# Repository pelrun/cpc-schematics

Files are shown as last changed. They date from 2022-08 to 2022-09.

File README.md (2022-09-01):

## Amstrad CPC6128 version 2 (MC0020x) schematic and pcb.

This is intended to be a reasonably accurate KiCad 6 transcription of the version 2 6128 pcb, with the 40010 Gate Array and the 24-pin disk data separator. The Amstrad service manuals don't bother to document this version, instead providing a mishmash of earlier and later revision schematics and pcb track layouts.

There are some liberties taken due to practical difficulties in reading the top layer of the PCB, so here's the priorities of this version:

- Schematic should match as closely as possible to the real board.
- All parts and part references and logical connectivity should match exactly.
- Part and via placement should match as closely as possible.
- Track routing should match closely on both sides of the pcb; all vias should be connected to the correct nets.
- Exact track poses may vary; original layout was done by hand and has varying angles; kicad layout is kept at 45 degrees.
- Track widths aren't correct everywhere; while the ground and power nets are handled by a netclass, a bunch of the tracks in the audio circuit need to have their widths manually adjusted.

Most part values should be correct, but I've not yet bothered to check any resistors - all values were copied from corresponding parts identified in the official schematics for the other revisions. Real values may be different, and additional resistors that are present but not documented elsewhere have been left with a value of "?".

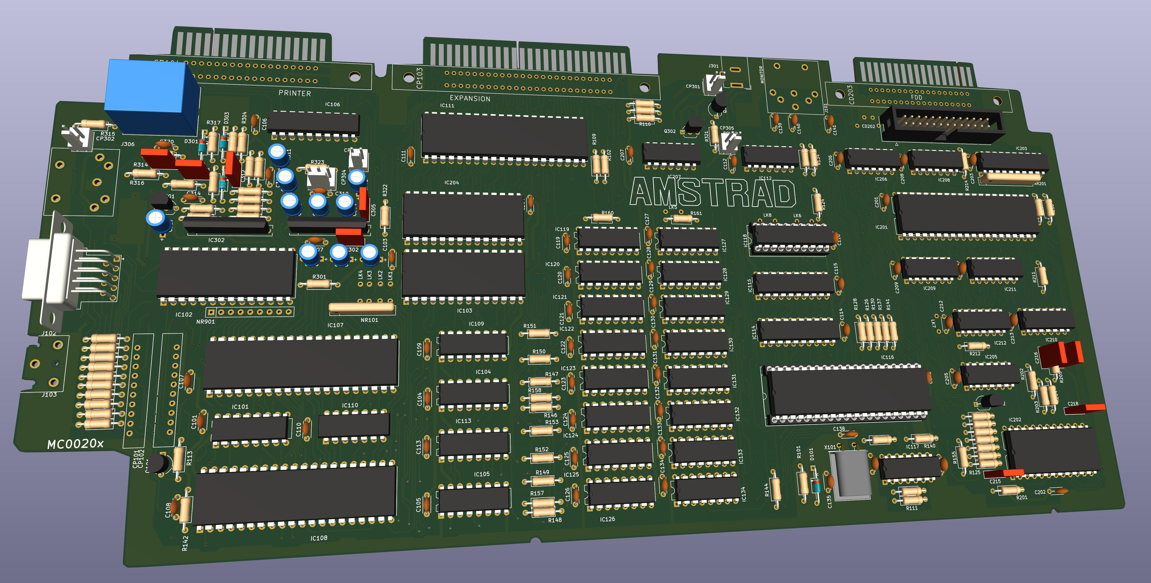
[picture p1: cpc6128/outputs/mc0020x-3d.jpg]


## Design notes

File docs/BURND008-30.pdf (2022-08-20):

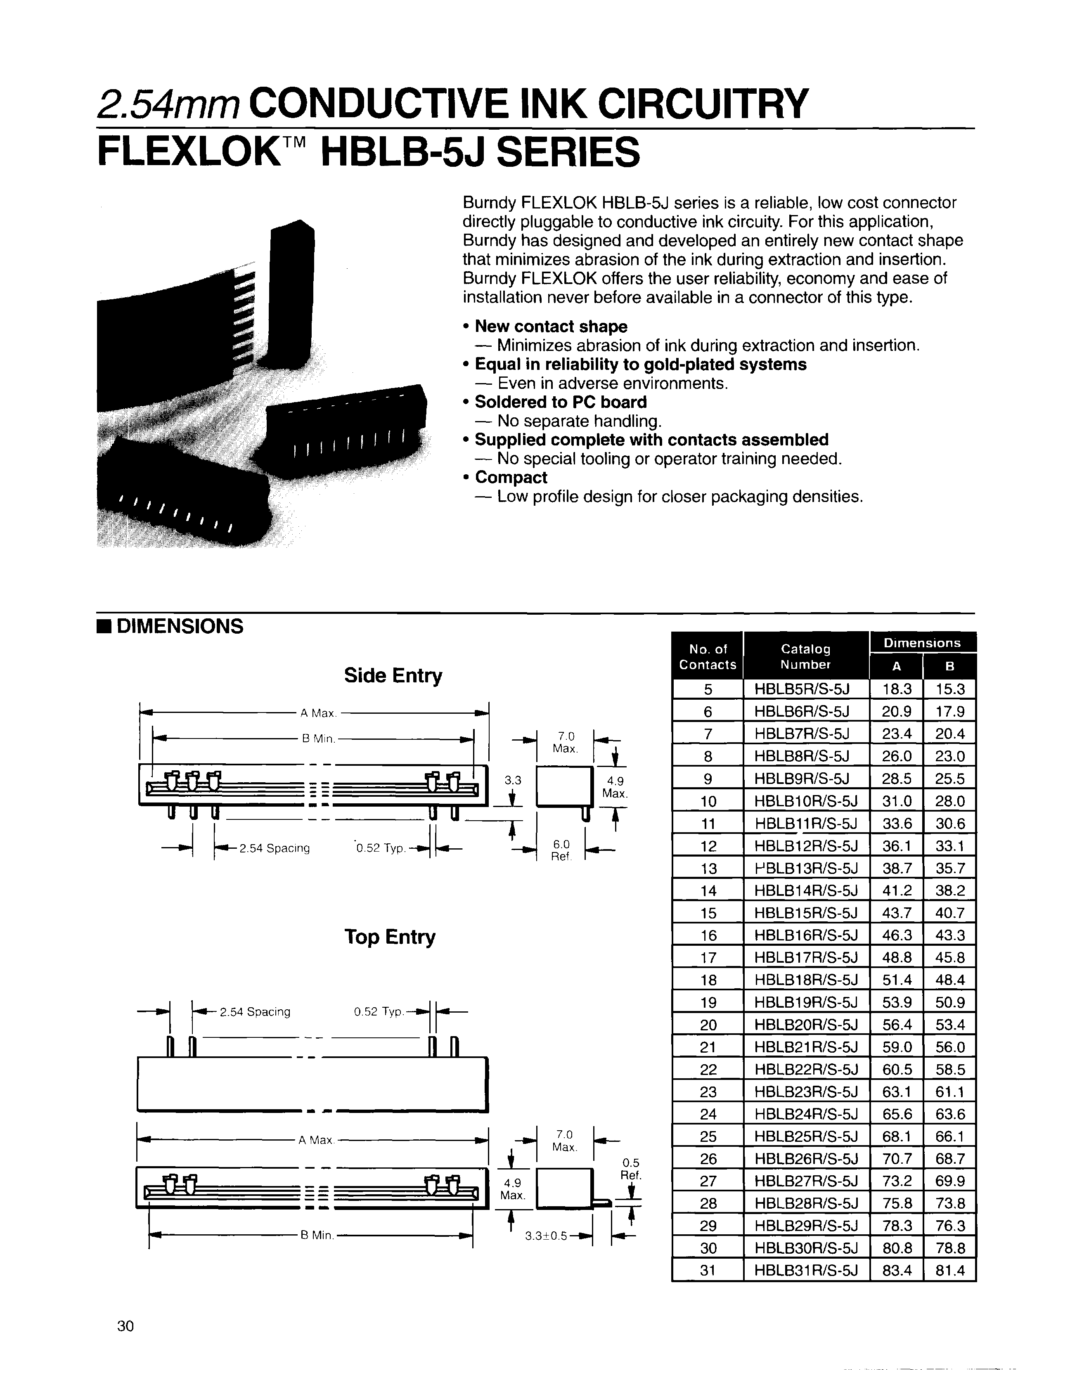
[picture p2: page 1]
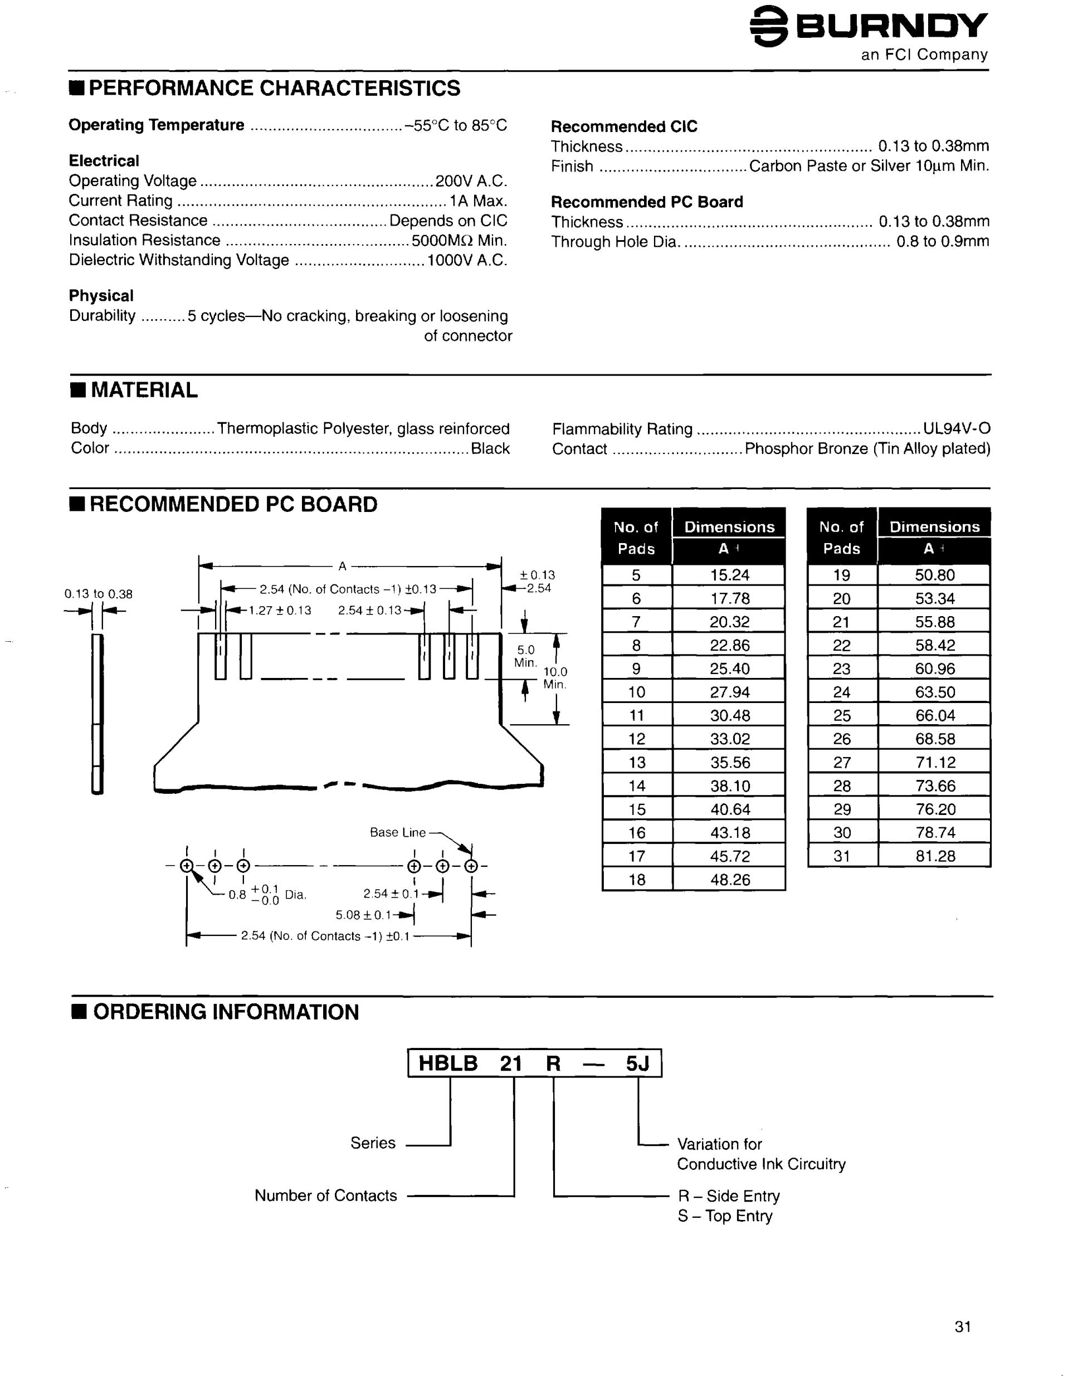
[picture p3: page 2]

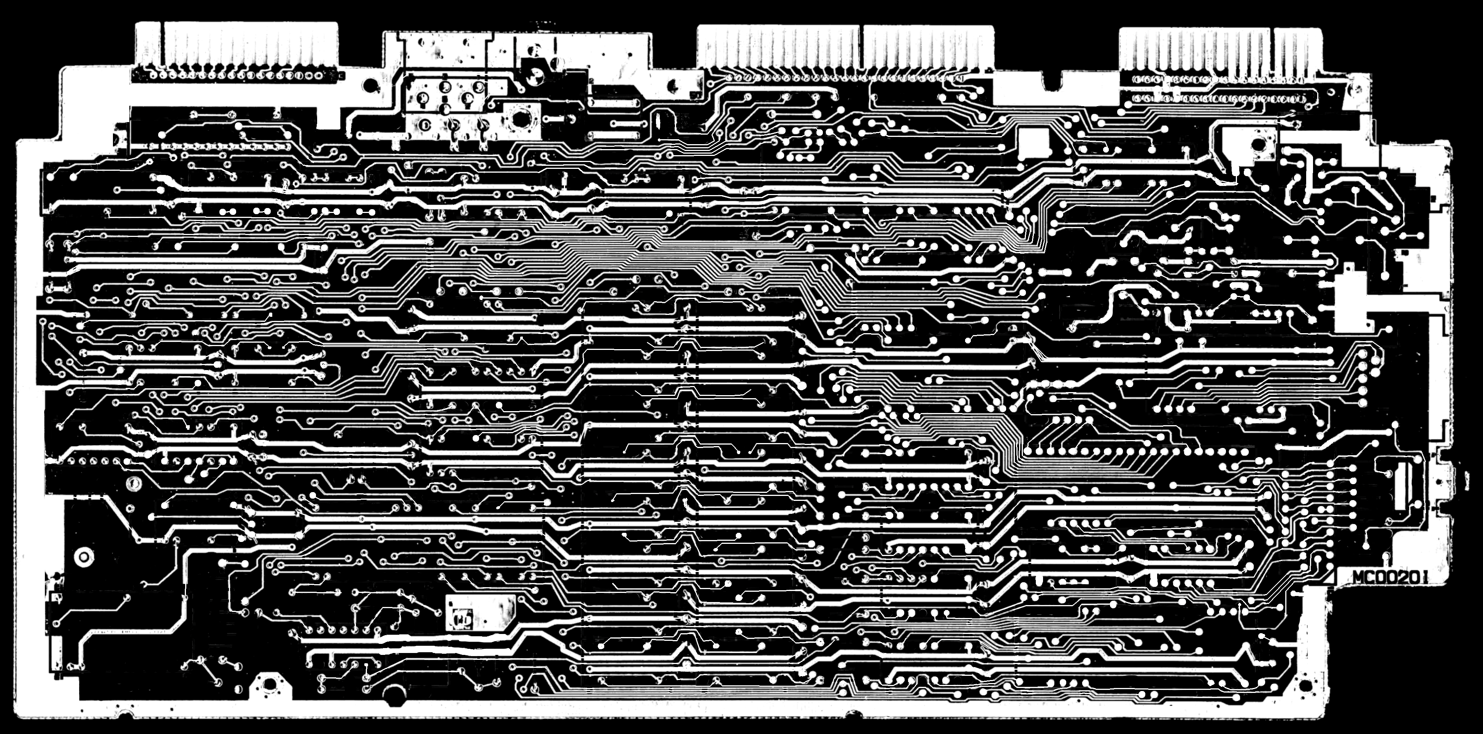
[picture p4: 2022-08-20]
docs/mc0020i-bcu.png

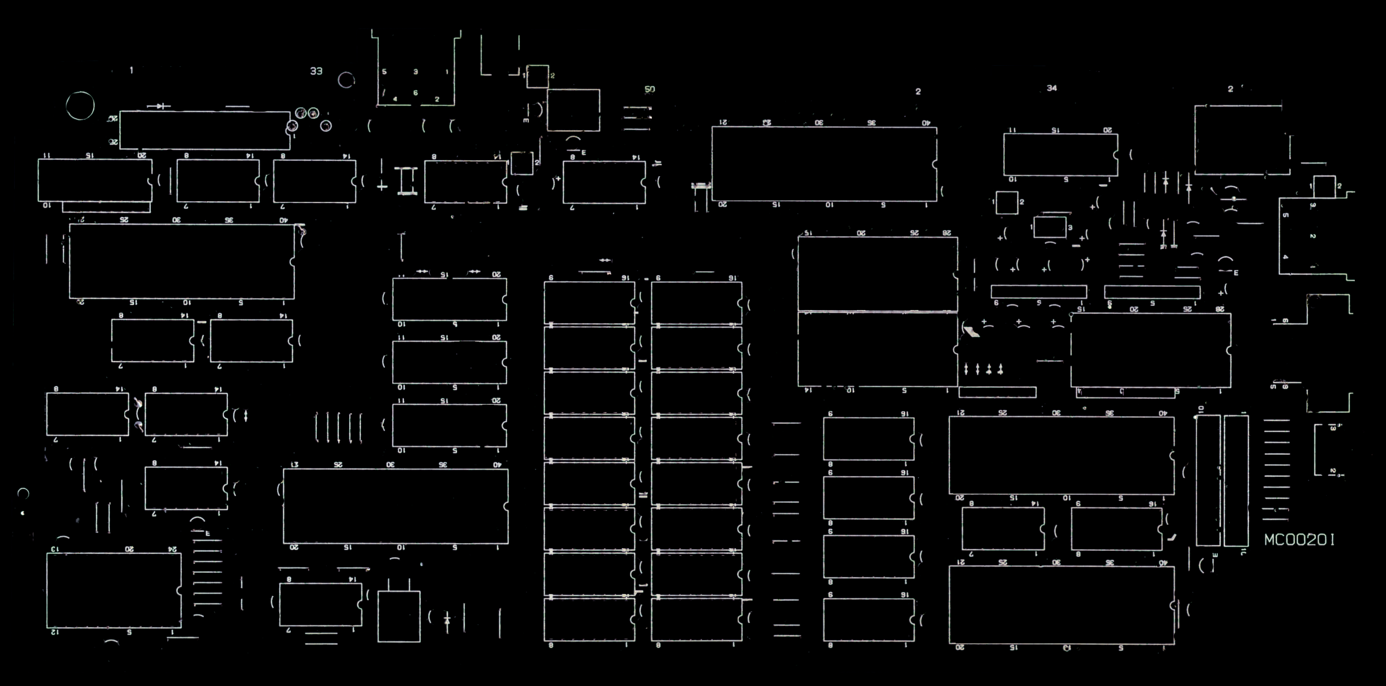
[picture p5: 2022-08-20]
docs/mc0020i-bsilks.png

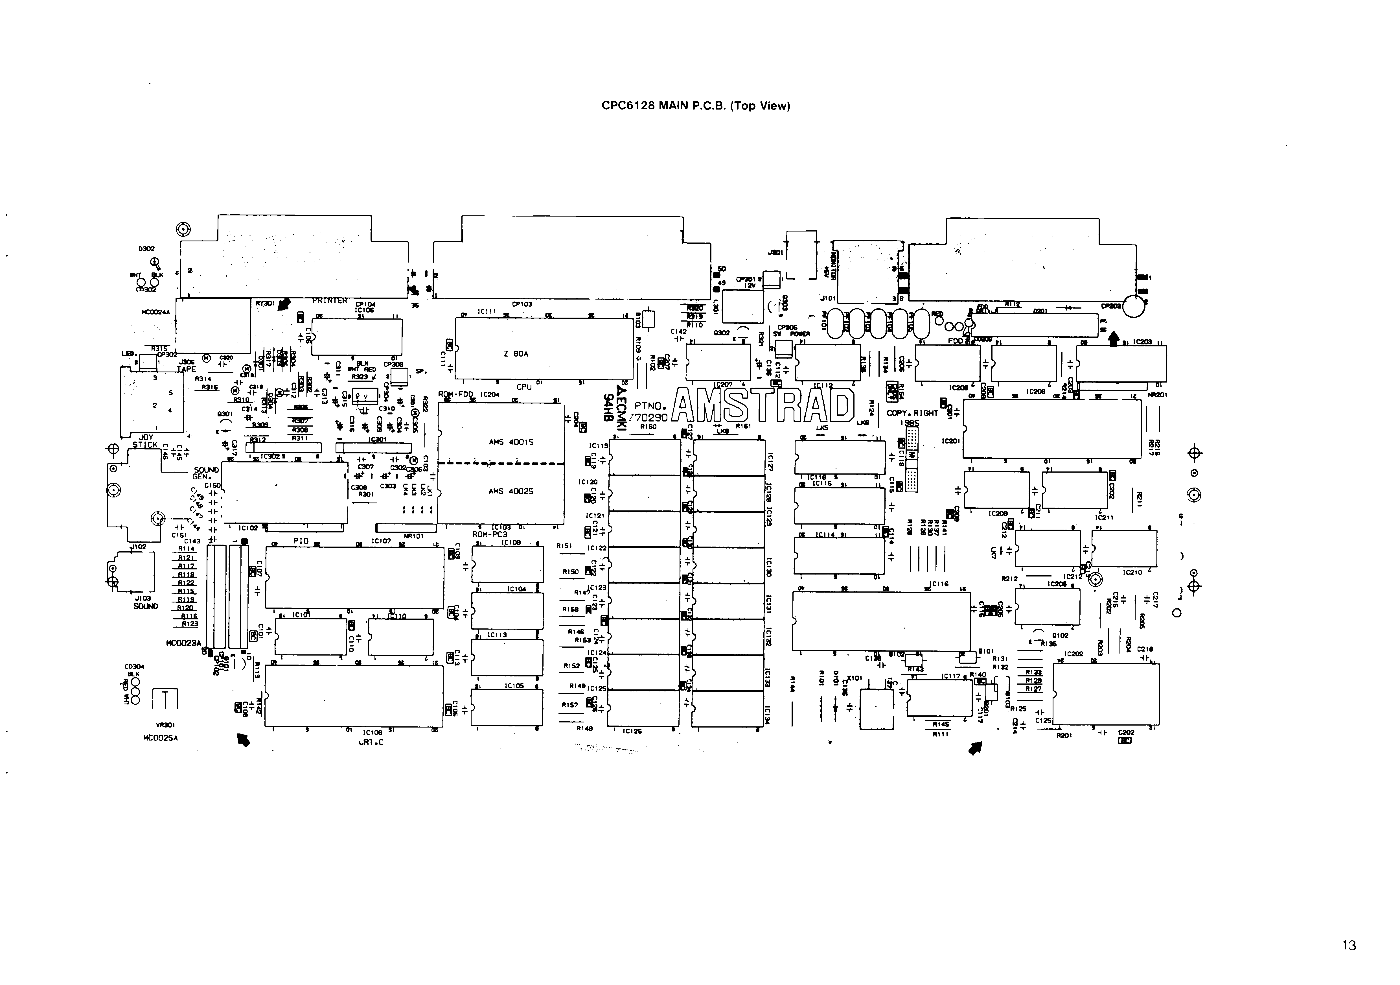
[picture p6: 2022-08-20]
docs/mc0023a-silk.png

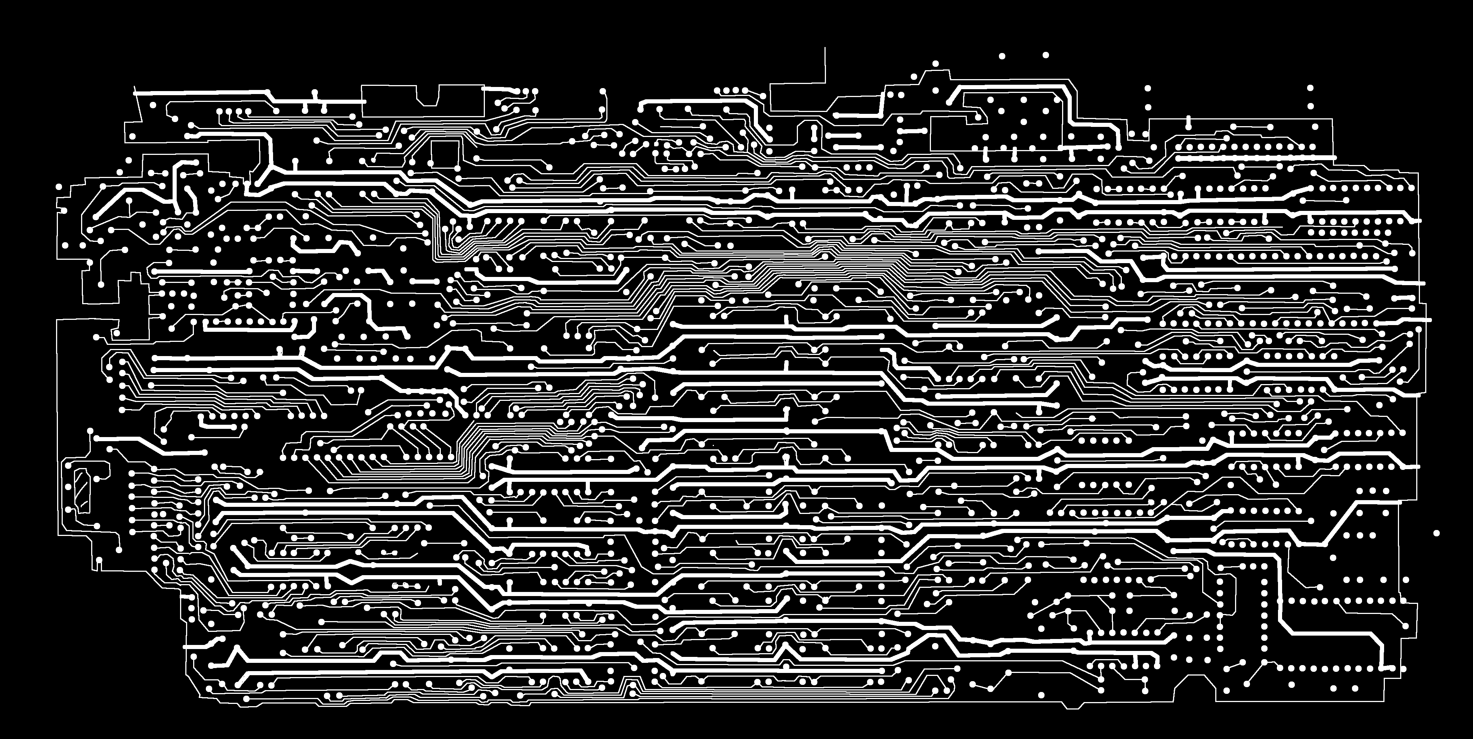
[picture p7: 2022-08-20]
docs/new-bcu.png

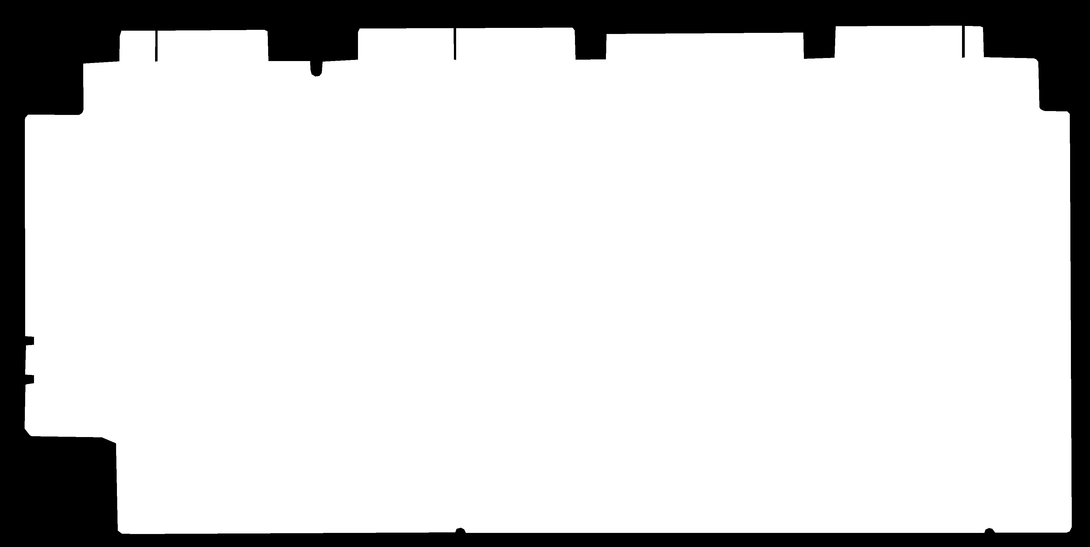
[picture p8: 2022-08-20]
docs/new-edgecuts.png

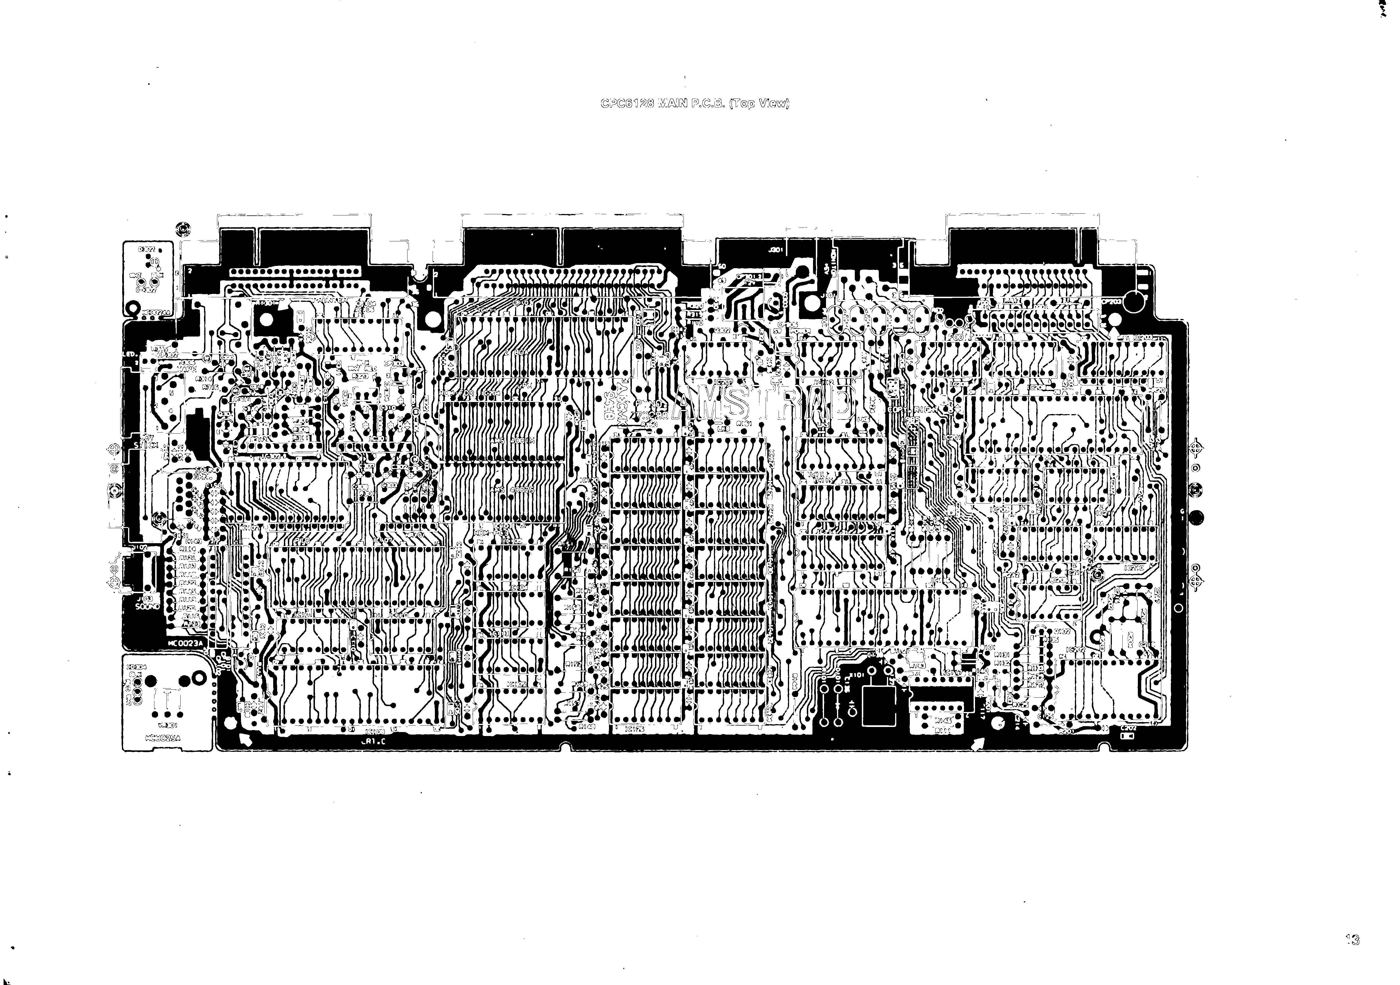
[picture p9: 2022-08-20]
docs/mc0023a-fcu.png

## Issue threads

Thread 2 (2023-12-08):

CAS0 and CAS1 swapped

Kyp069, 2023-12-08:
Hi, first thank you for the project.

I think I have found a mistake:

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

In IC118:
CAS0 is pin 17
CAS1 is pin 16
But they are swapped in your schematic.
I have also checked against original PCB.

pelrun, 2023-12-11:
Yeah, they're probably swapped. However the connectivity is right - pin 16 goes to the left hand bank (IC119 and up) and pin 17 goes to the right (IC127 and up).

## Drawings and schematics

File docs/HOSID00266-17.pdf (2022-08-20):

# DC電源ジャック

## DC Power Jacks

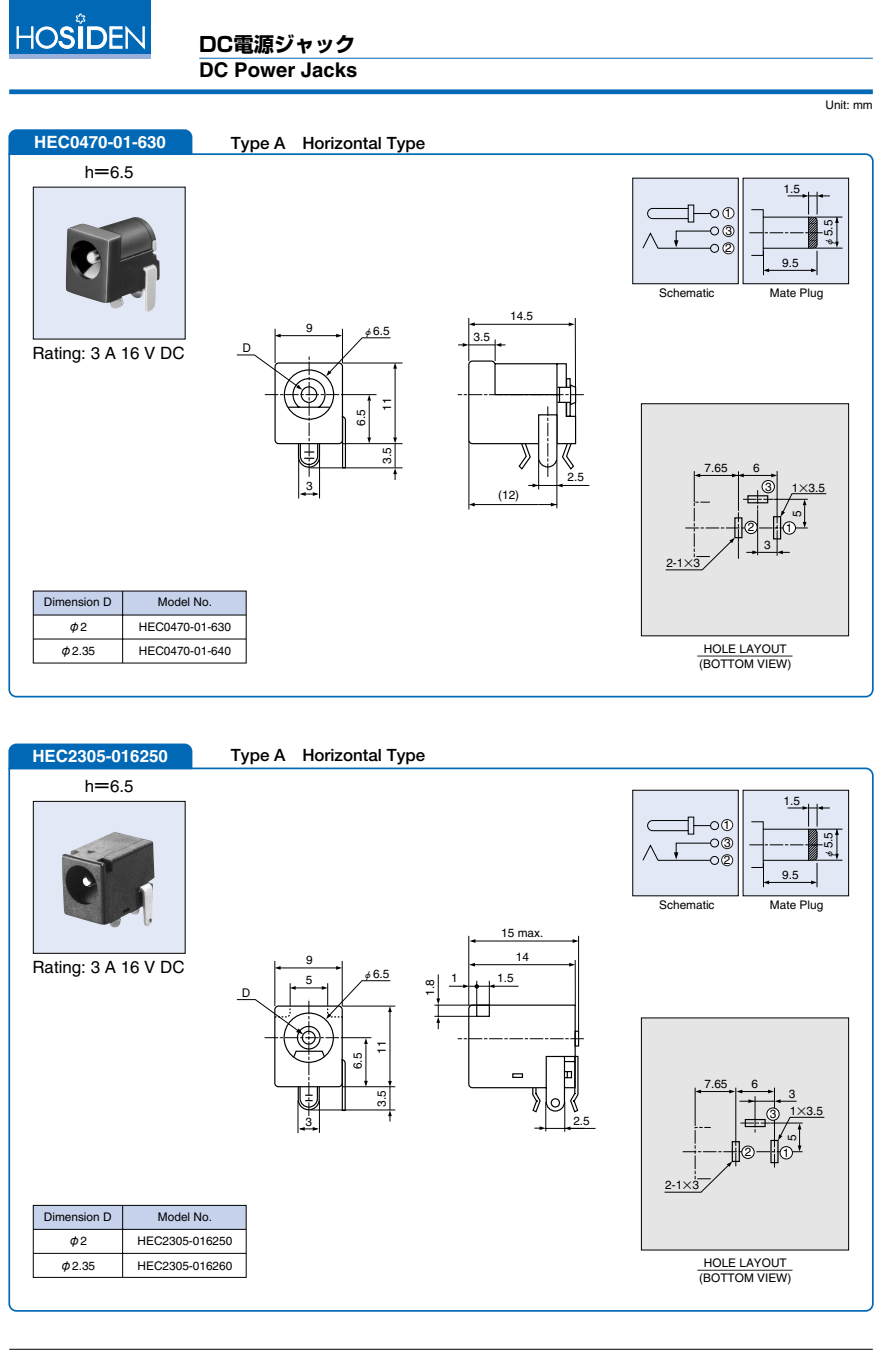
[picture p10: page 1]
Unit: mm; Schematic; Mate Plug; HEC0470-01-630; Rating: 3 A 16 V DC; HOLE LAYOUT (BOTTOM VIEW); HEC2305-016250; 15 max.

Type A　Horizontal Type

Dimension D | Model No.

φ2 | HEC0470-01-630

φ2.35 | HEC0470-01-640

φ2 | HEC2305-016250

φ2.35 | HEC2305-016260

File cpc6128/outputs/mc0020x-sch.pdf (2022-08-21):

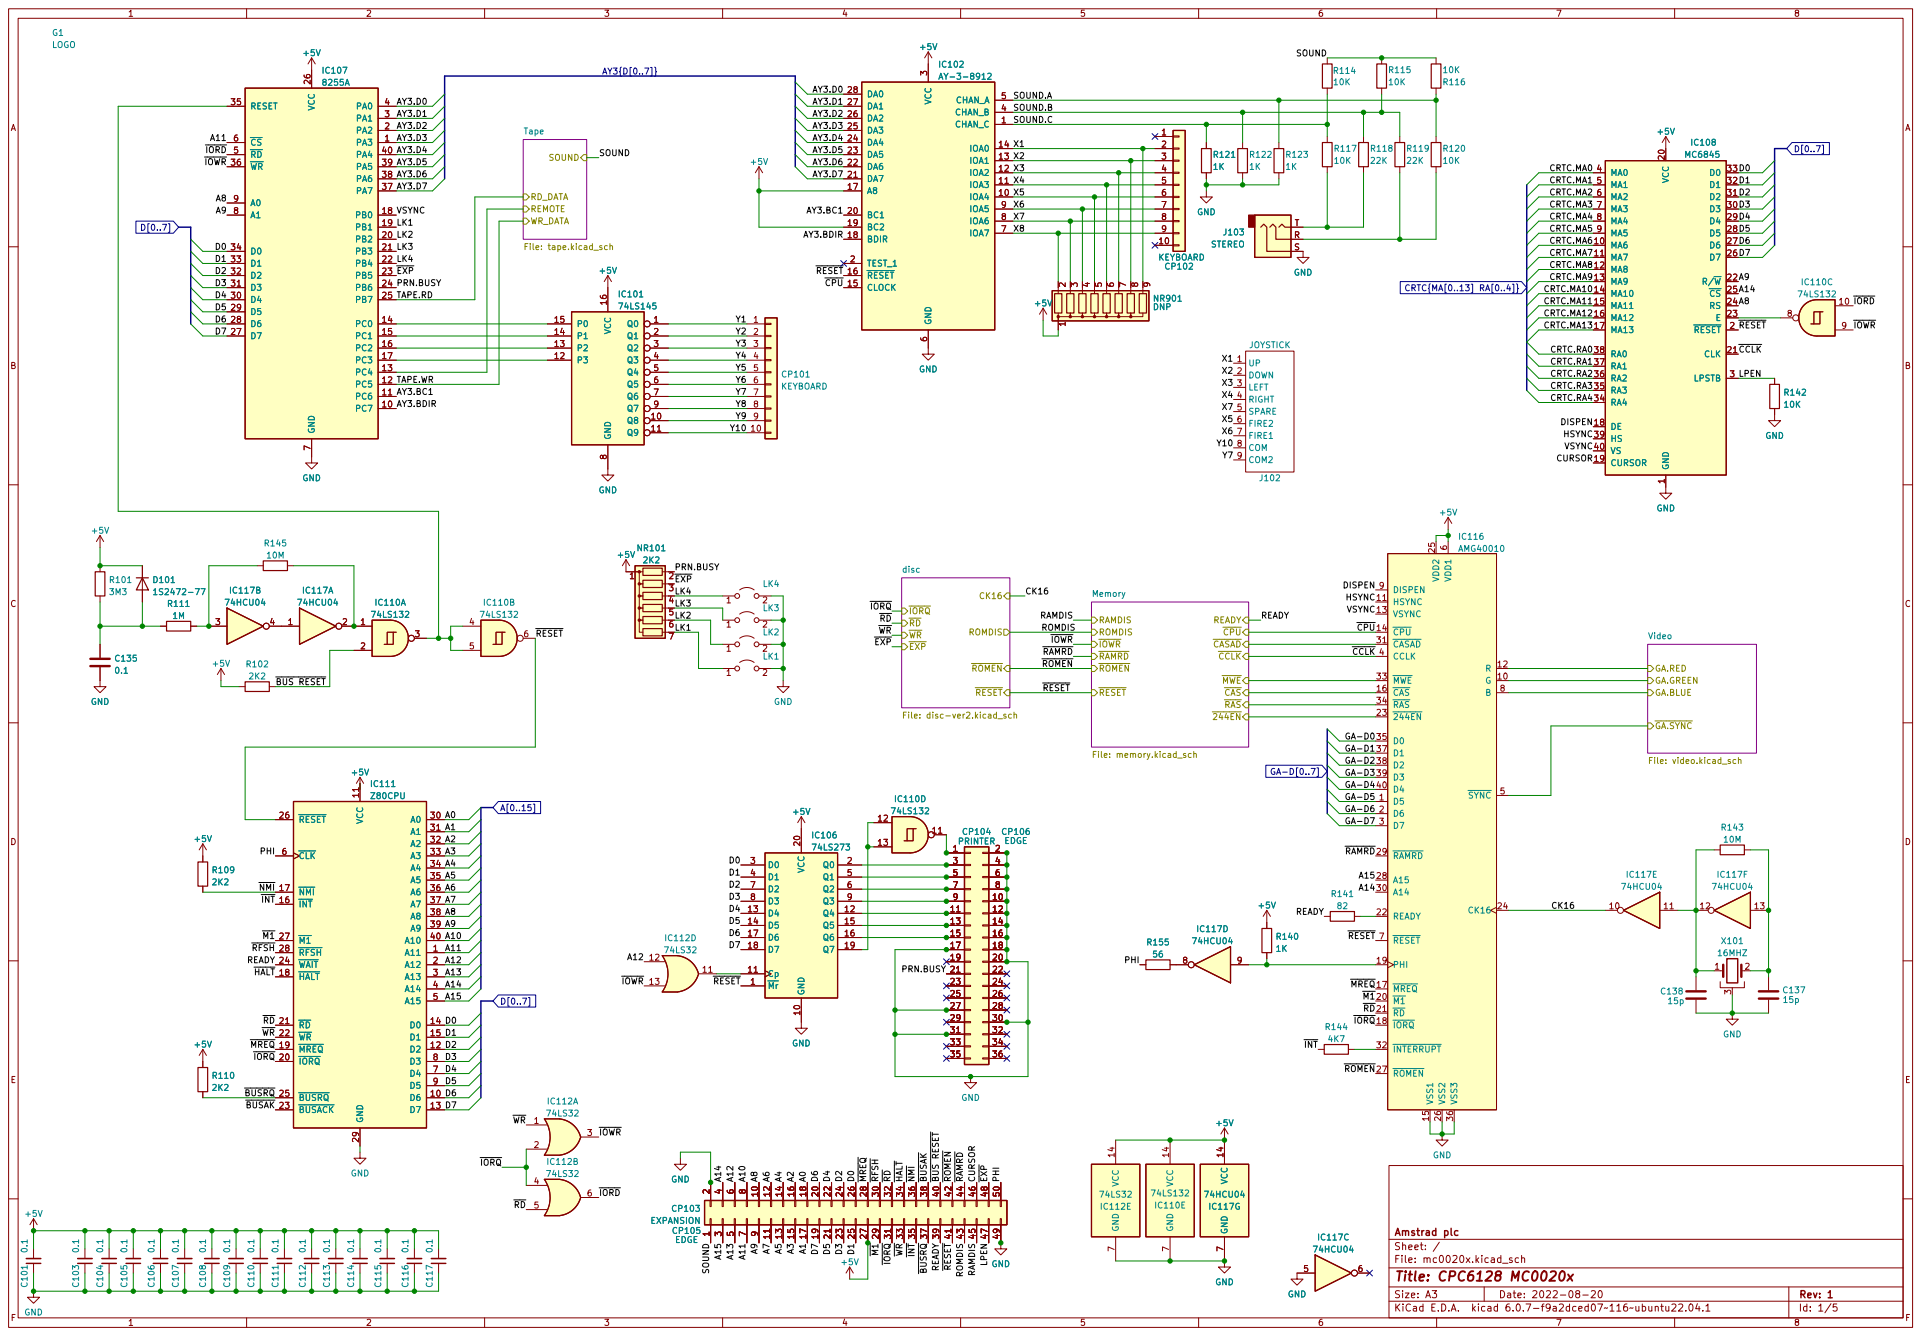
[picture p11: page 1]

1 MA6 10 MA7 11 MA8 12 MA9 13 MA10 14 MA11 15 MA12 16 MA13 17 DE 18 CURSOR 19 ~{RESET} 2 VCC 20 CLK

~{RESET} CRTC.MA8 CRTC.MA10 CRTC.MA7 DISPEN

~{GA.SYNC} Video File: video.kicad_sch ROMDIS

File: mc0020x.kicad_sch Sheet: / Amstrad plc

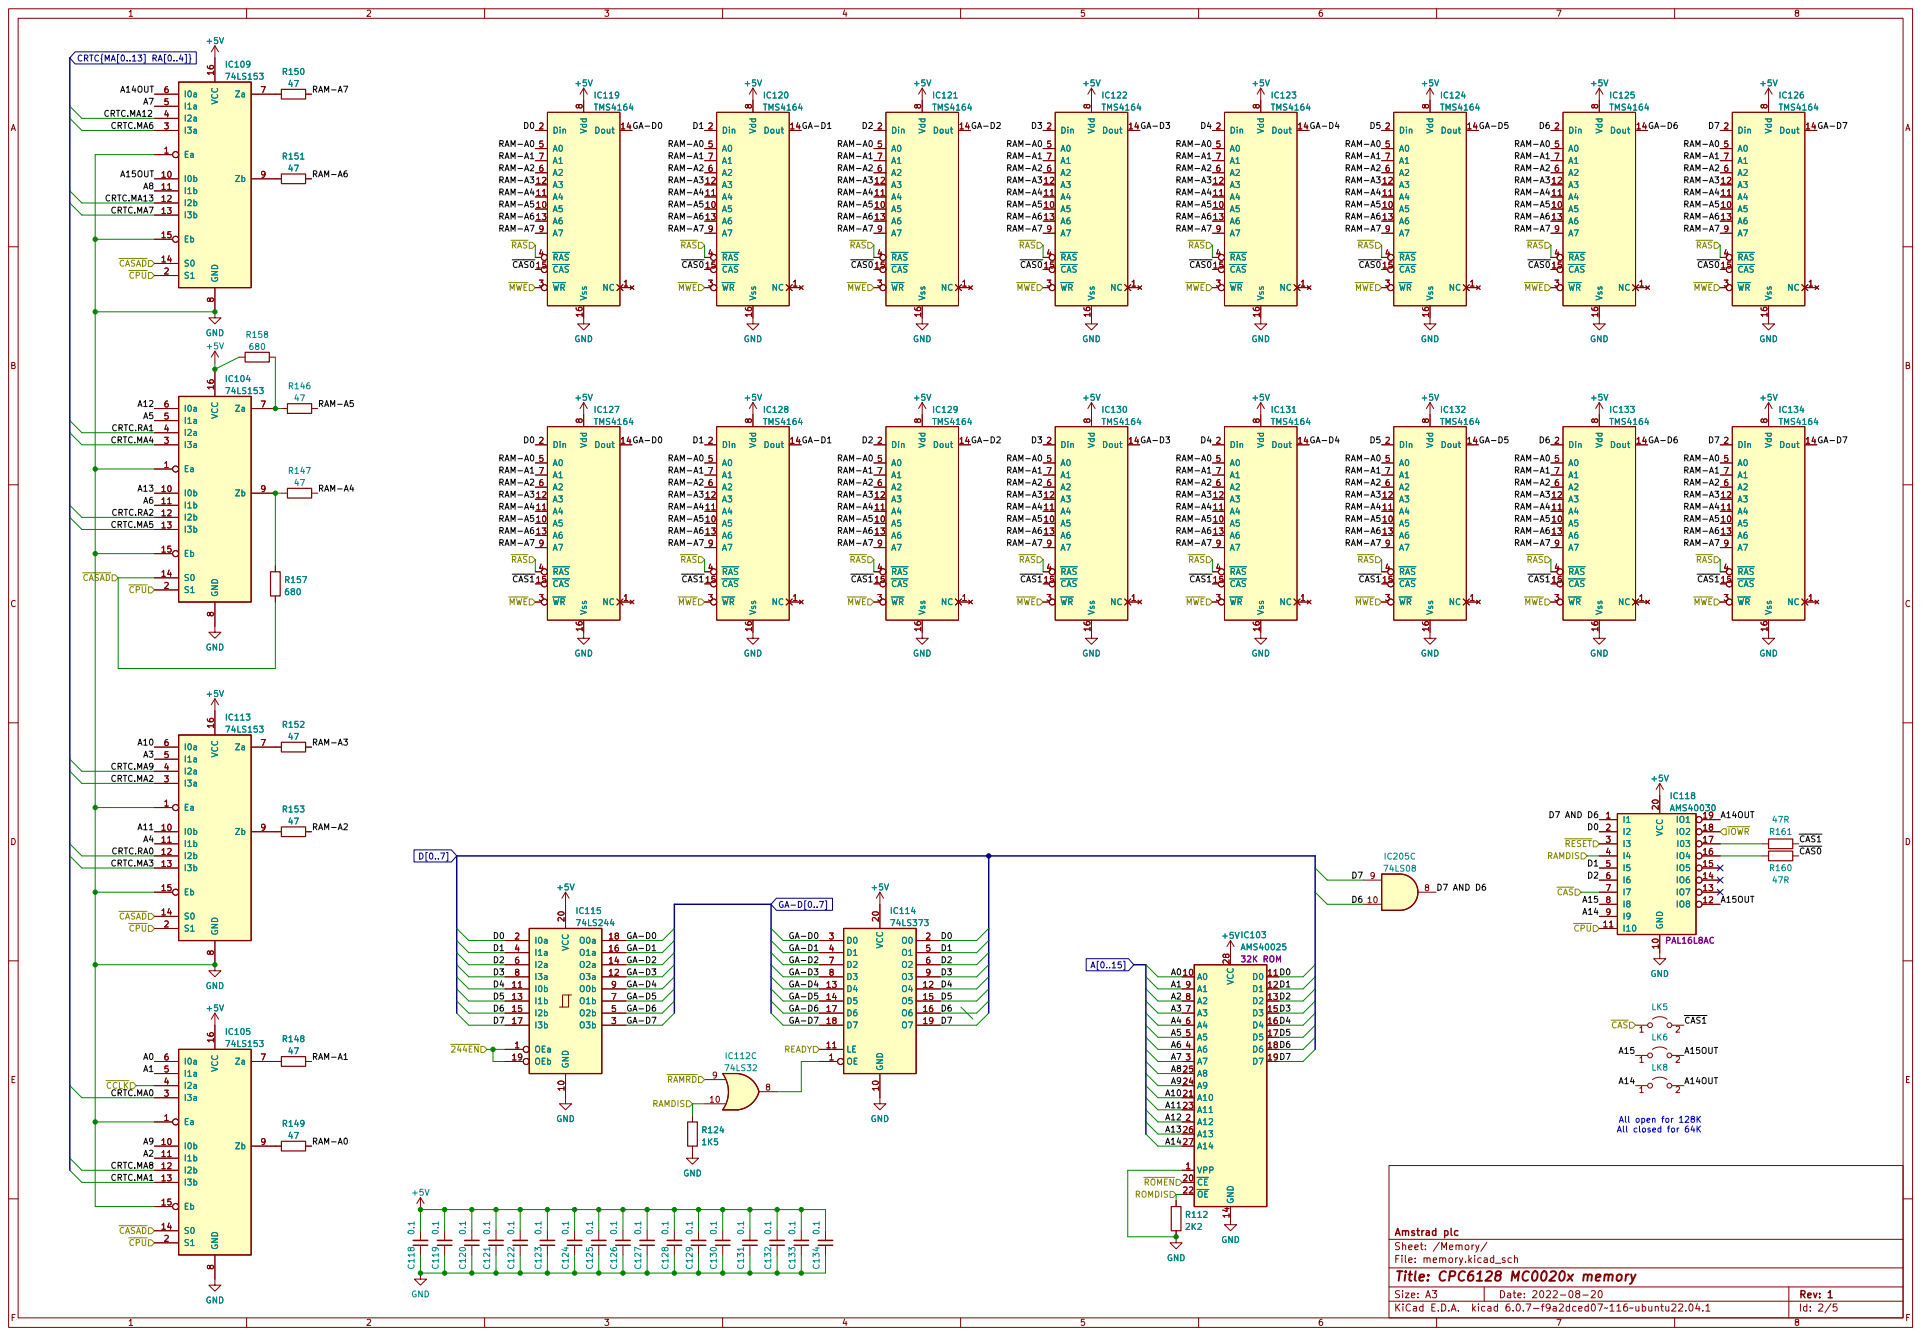
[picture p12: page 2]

8 A7 9 +5V GND GND GND GND

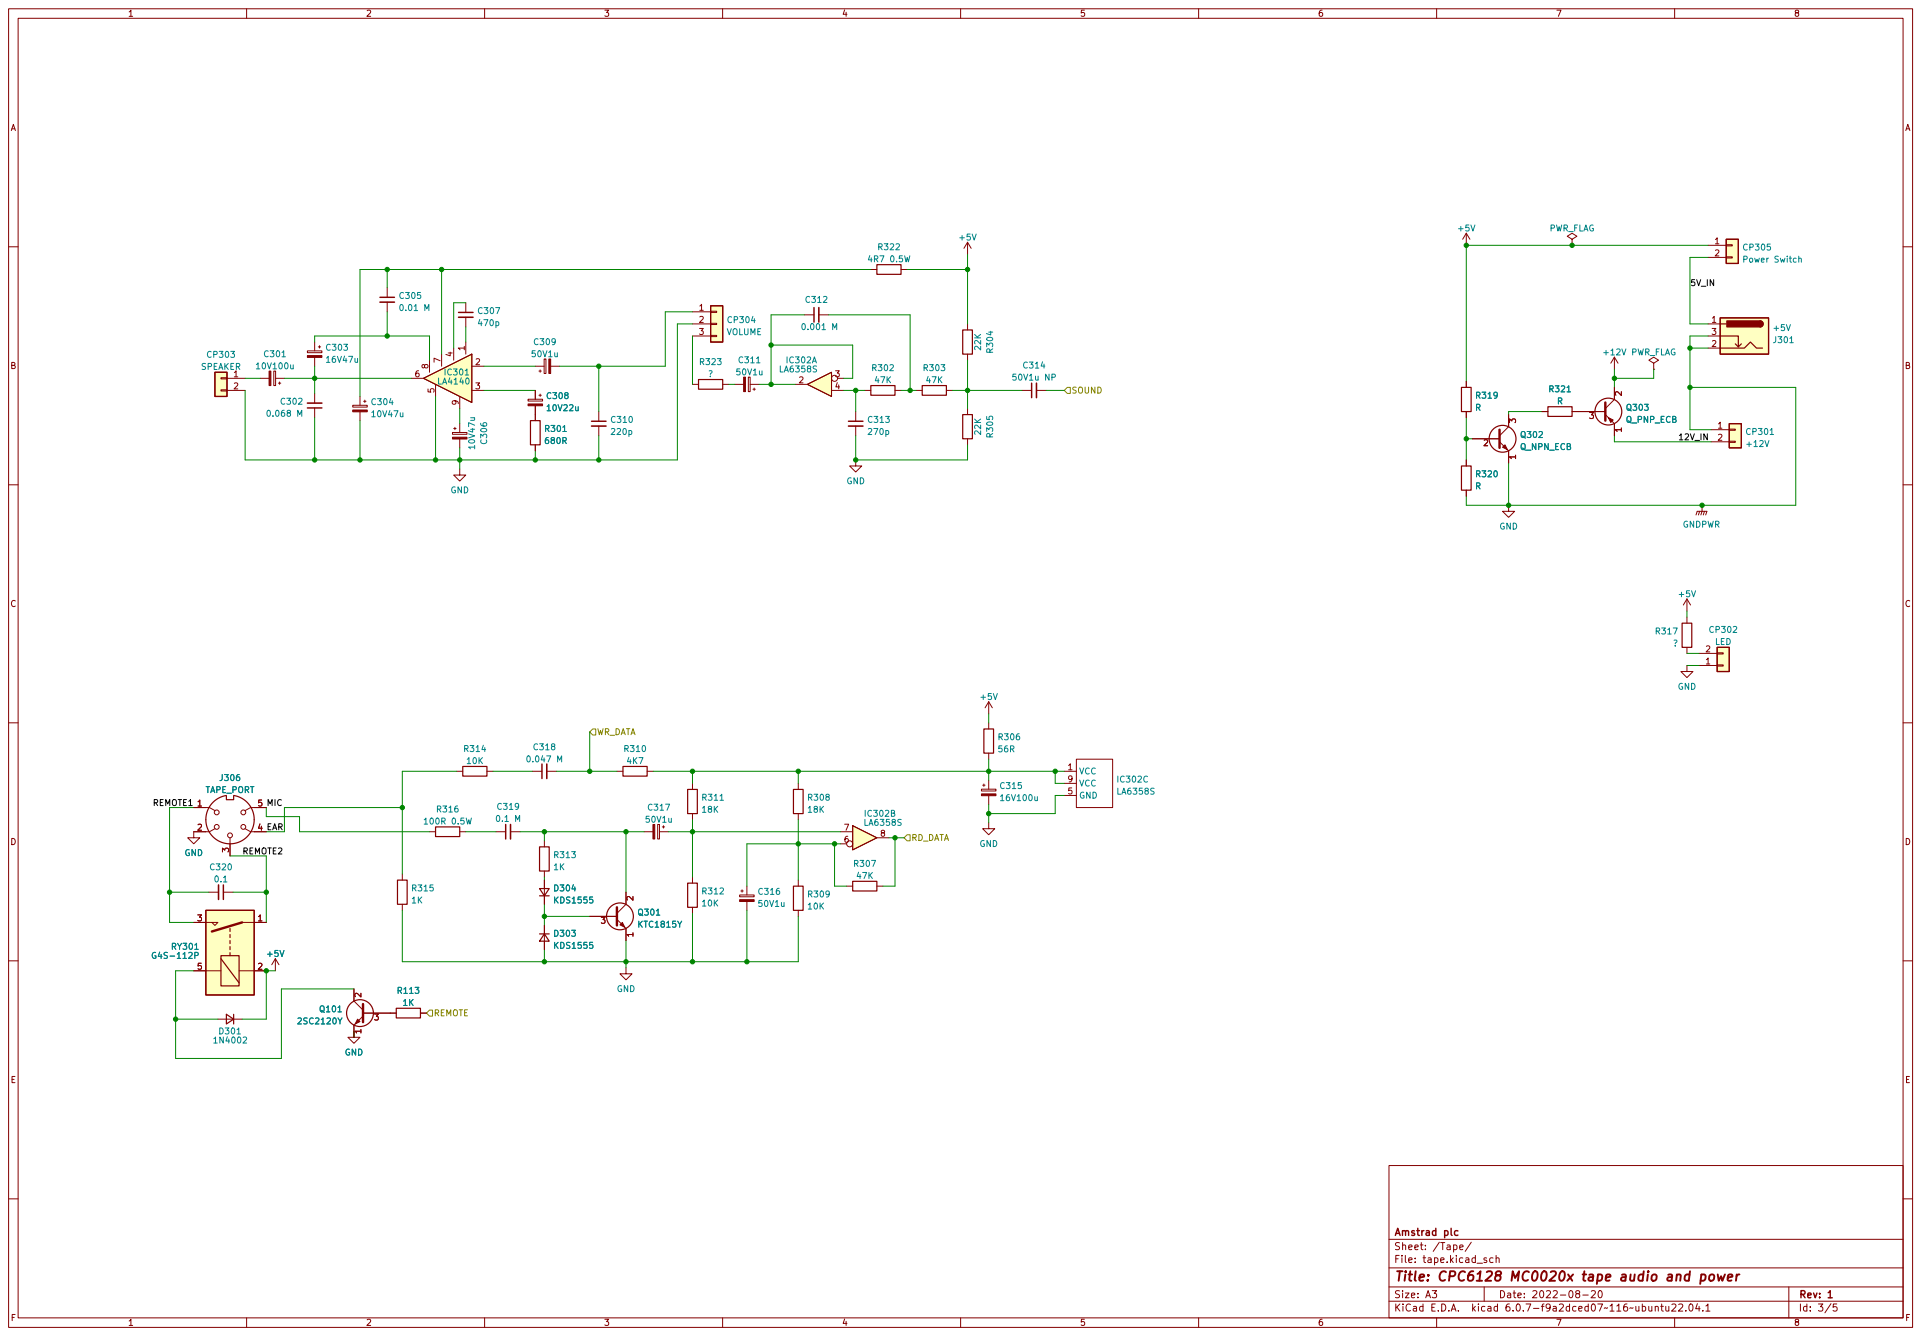
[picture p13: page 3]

Amstrad plc
Sheet: /Tape/
File: tape.kicad_sch
Id: 3/5 Title: CPC6128 MC0020x tape audio and power

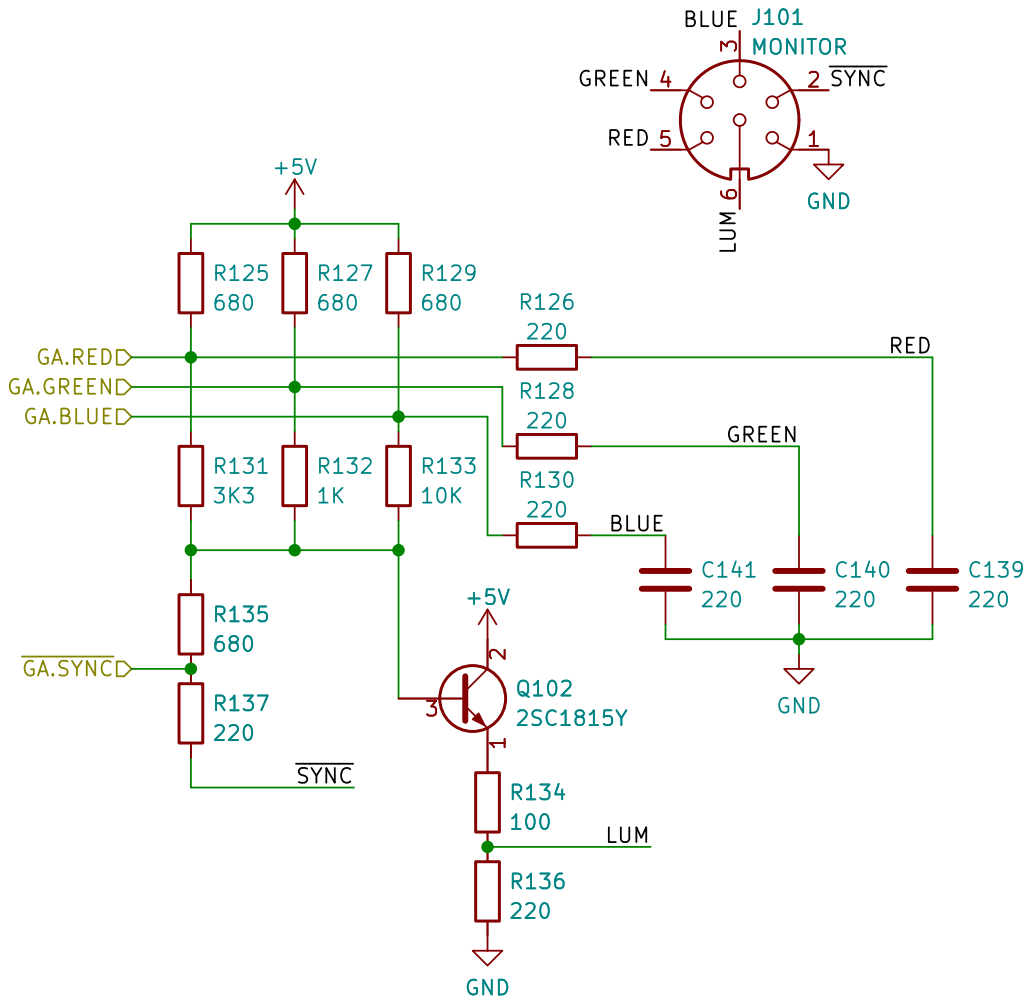
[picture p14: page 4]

File: video.kicad_sch Sheet: /Video/ Amstrad plc R137

Id: 4/5 Title: CPC6128 MC0020x Monitor output

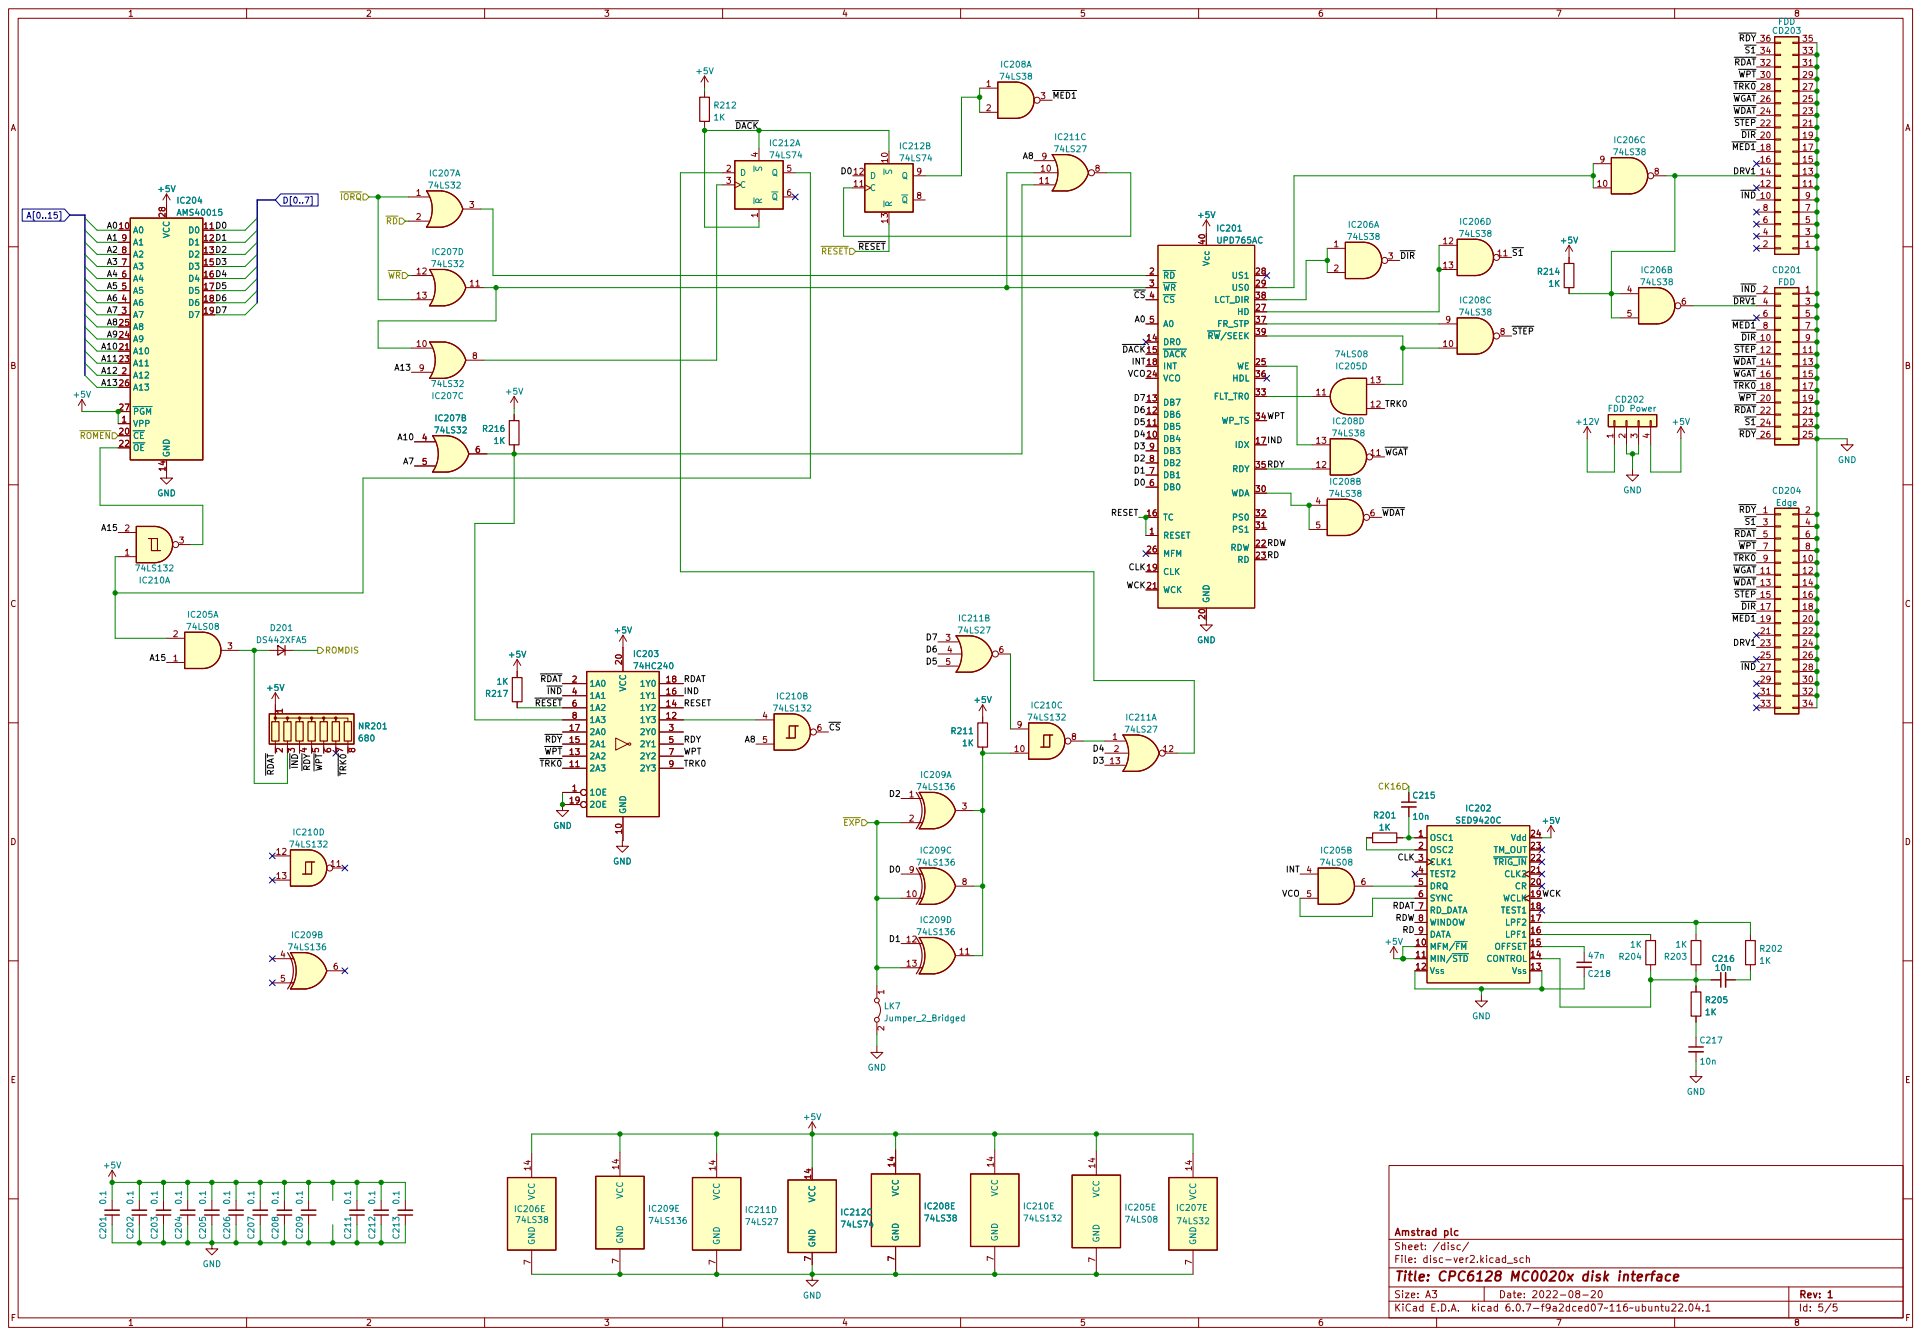
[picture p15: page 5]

File: disc-ver2.kicad_sch Sheet: /disc/ Amstrad plc VCC 14 GND

Id: 5/5 Title: CPC6128 MC0020x disk interface

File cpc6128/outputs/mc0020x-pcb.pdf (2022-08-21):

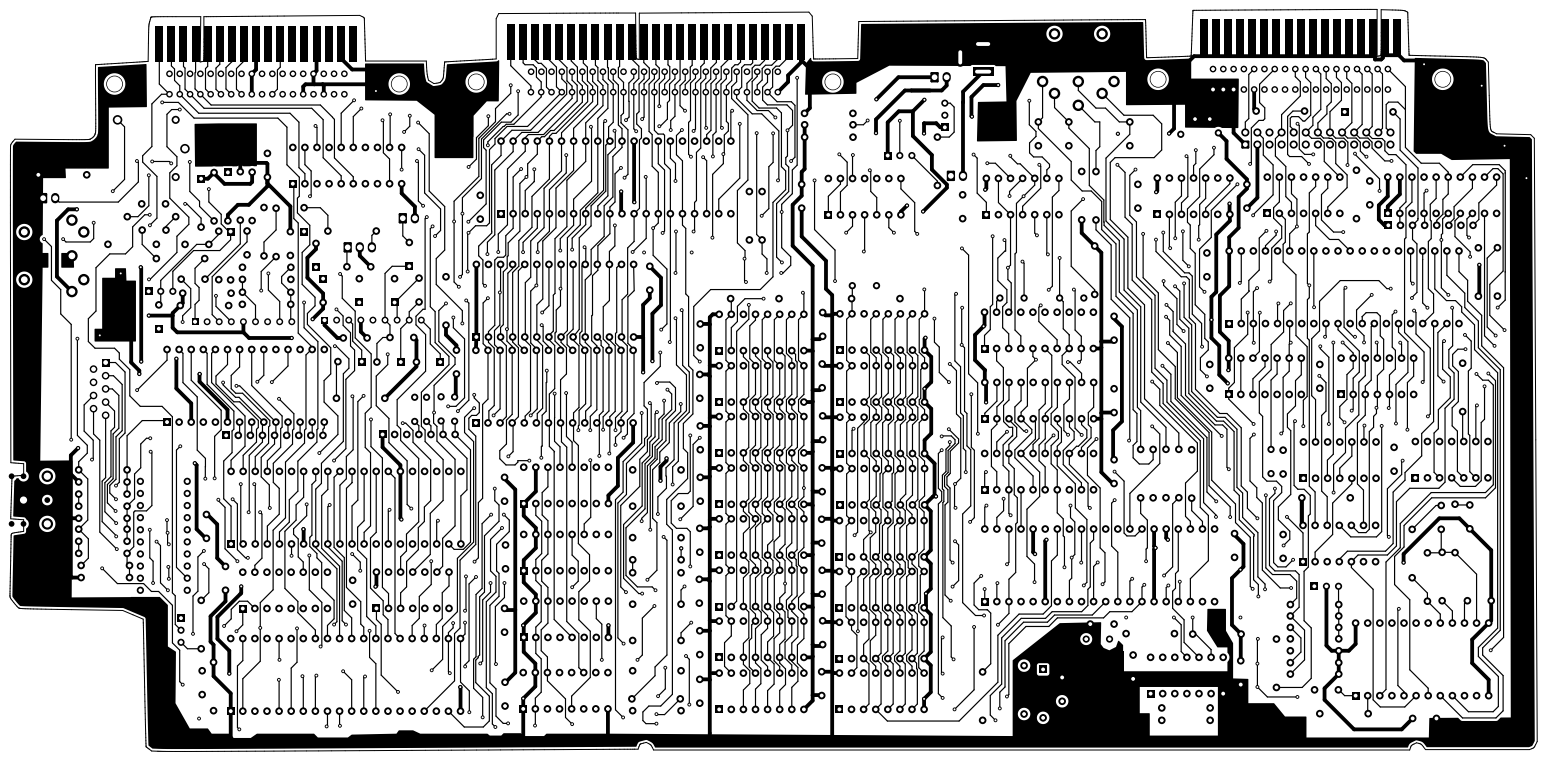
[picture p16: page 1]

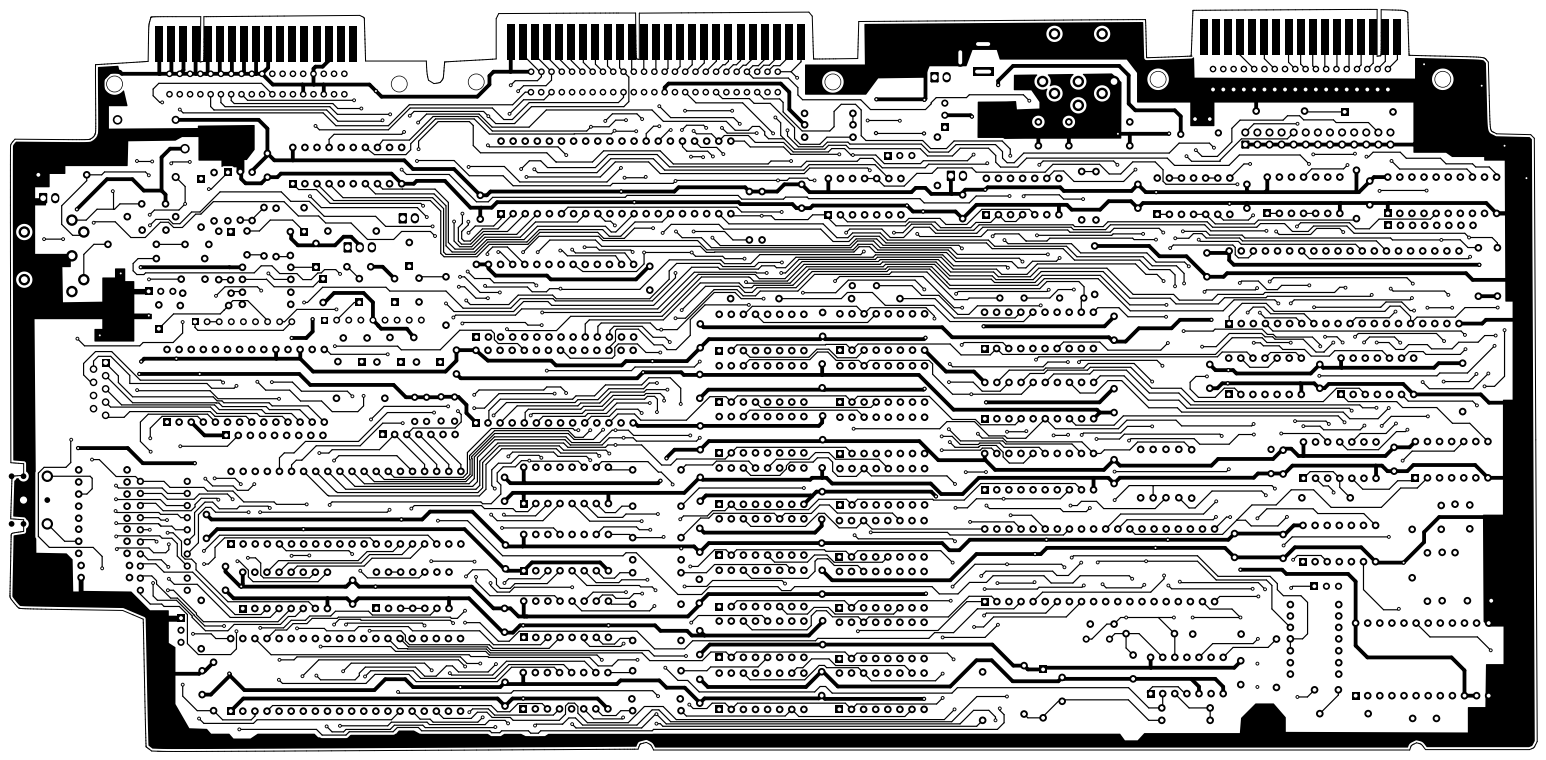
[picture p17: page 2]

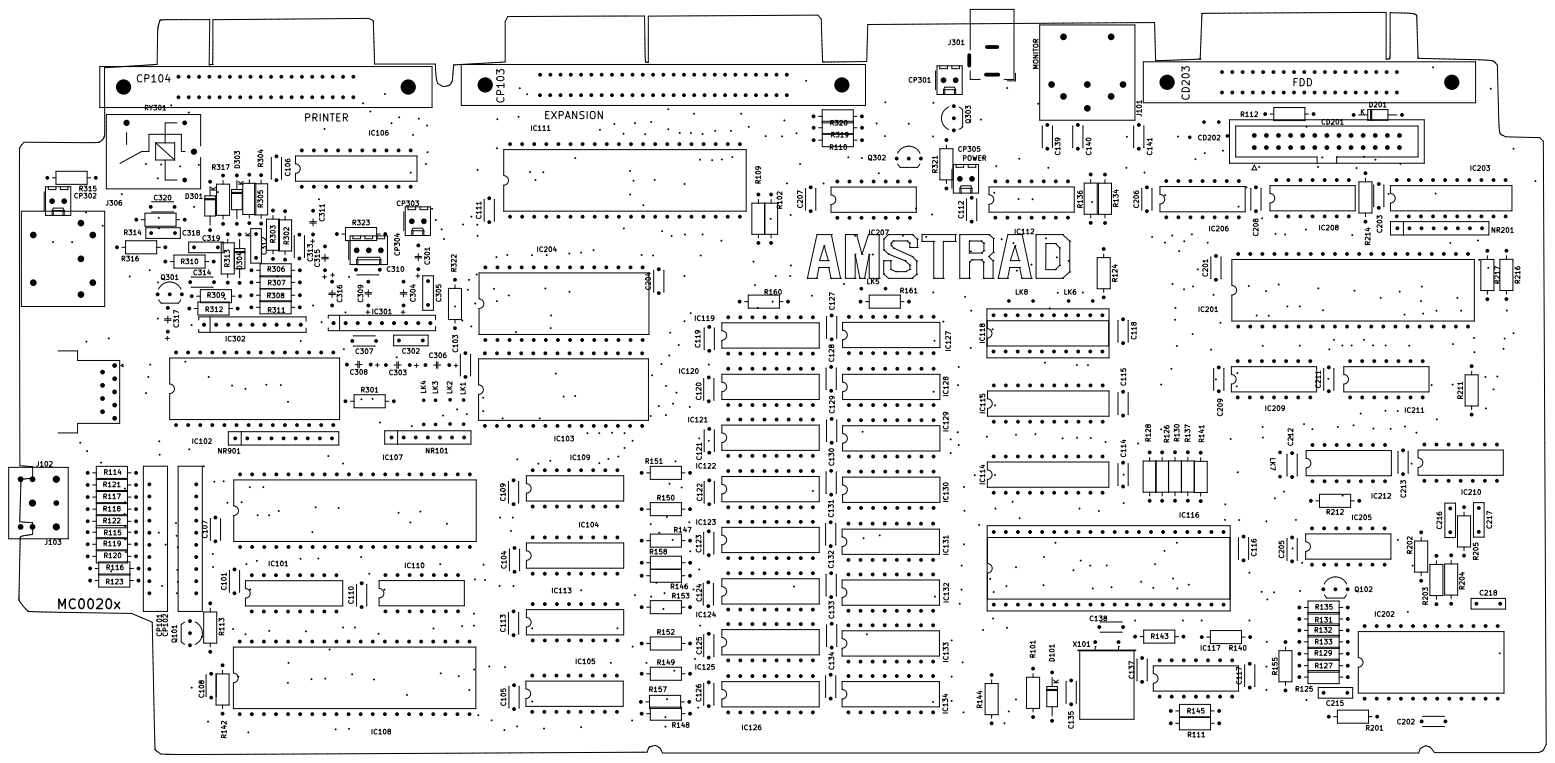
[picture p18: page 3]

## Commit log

2022-08-20 Initial release
    [disc-ver2.kicad_sch, mc0020x.kicad_sch, memory.kicad_sch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]
2022-08-20 Update title blocks
    [disc-ver2.kicad_sch, mc0020x.kicad_sch, memory.kicad_sch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]
2022-08-20 Fix edge connector properties
2022-08-21 Fixes from new top pcb image
    [disc-ver2.kicad_sch, mc0020x.kicad_sch, tape.kicad_sch]
2022-09-01 Minor cleanups
    [disc-ver2.kicad_sch, mc0020x.kicad_sch, tape.kicad_sch]
2025-07-12 Correct C136 (missing) and C314 (wrong footprint) Thanks @orzel!
    Also migrated to KiCad 9.
    [disc-ver2.kicad_sch, mc0020x.kicad_sch, memory.kicad_sch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]
2025-09-28 Fix swapped audio (thanks @orzel), tweaked some footprints
    PCB layout is unchanged, only affects schematic
